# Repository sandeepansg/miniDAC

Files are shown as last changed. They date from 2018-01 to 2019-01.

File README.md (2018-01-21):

<h1 align="center"> Arduino miniDAC Module </h1> <br>

## Table of Contents
- [About](#about)
- [Social](#social)
- [License](#license)
- [Acknowledgments](#acknowledgments)

## About





**Arduino miniDAC Module** is a unipolar digital to analog converter (DAC) module built arround [LTC®2633](http://www.linear.com/product/LTC2633), which is a family of dual 12-, 10-, and 8-bit voltage-output DACs with an integrated, high accuracy, low drift reference in an 8-lead TSOT-23 package.
<br>These DACs communicate via a 2-wire I2C-compatible serial interface operating in both the standard mode (clock rate of 100kHz) and the fast mode (clock rate of 400kHz).
<br>It is compatible with both 3.3V and 5V logic levels and uses [LTC2633](https://github.com/TamojitSaha/LTC2633) library developed by [Tamojit Saha](http://tamojit.tk) and [Sandeepan Sengupta](http://sandeepan.info)
<p align="center">
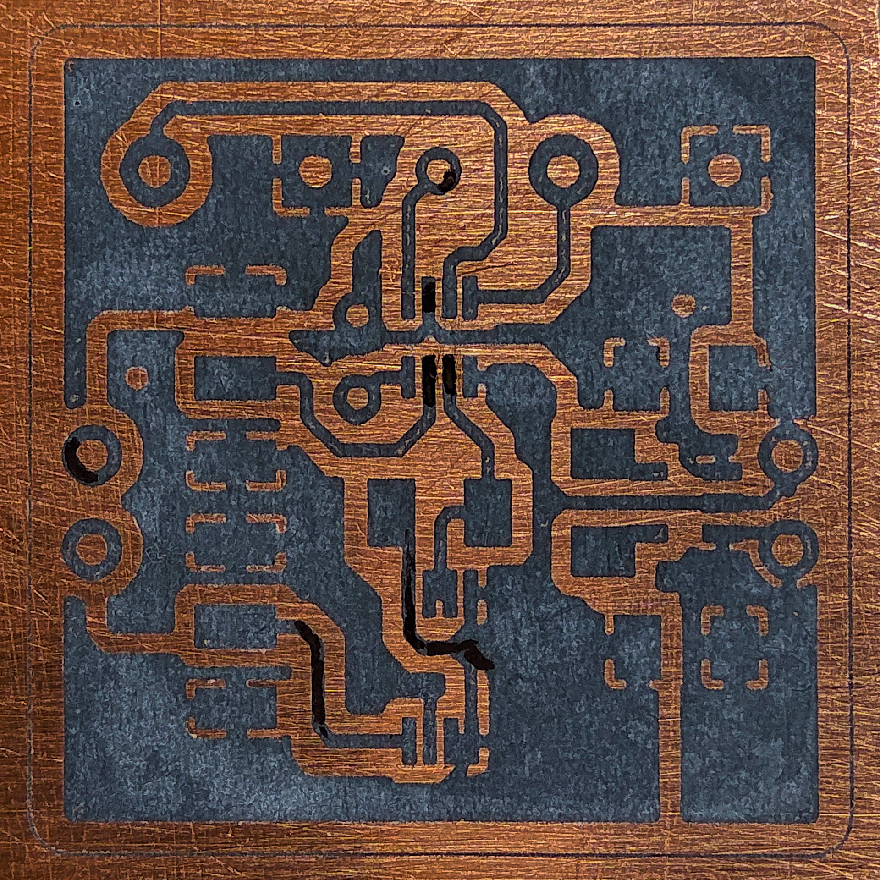
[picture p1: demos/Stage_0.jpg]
  &nbsp
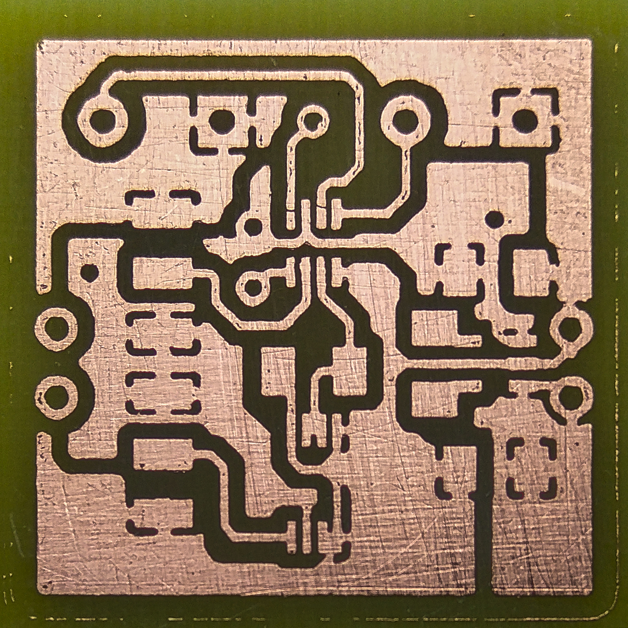
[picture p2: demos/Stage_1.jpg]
  &nbsp
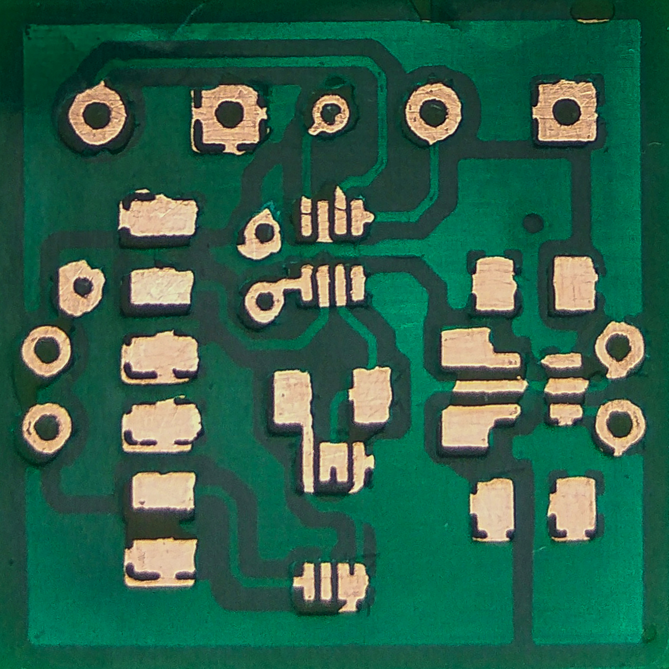
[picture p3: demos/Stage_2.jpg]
  &nbsp
</p>
<p align="center">
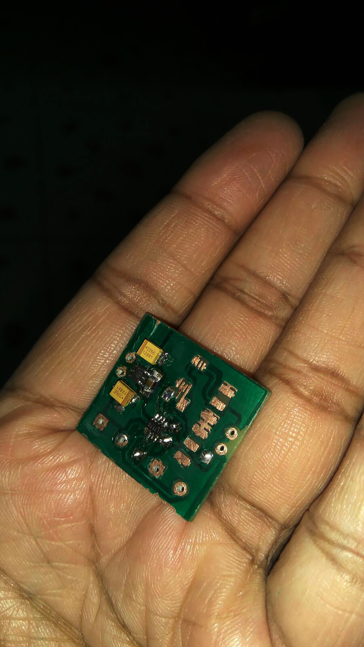
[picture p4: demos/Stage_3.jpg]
  &nbsp 
  &nbsp
</p>

## Social
Connect us here:
<br><br>
 <br>
 
<p> 
or <a href ="https://github.com/TamojitSaha/LTC2633/issues/new/">file an issue</a>. Feature requests are always welcome.</p>

## License
Contents of this repository are realeased under [CC-BY-NC-SA 4.0](./LICENSE.md) <br>


## Acknowledgments
Thanks to the contributors! :wink:

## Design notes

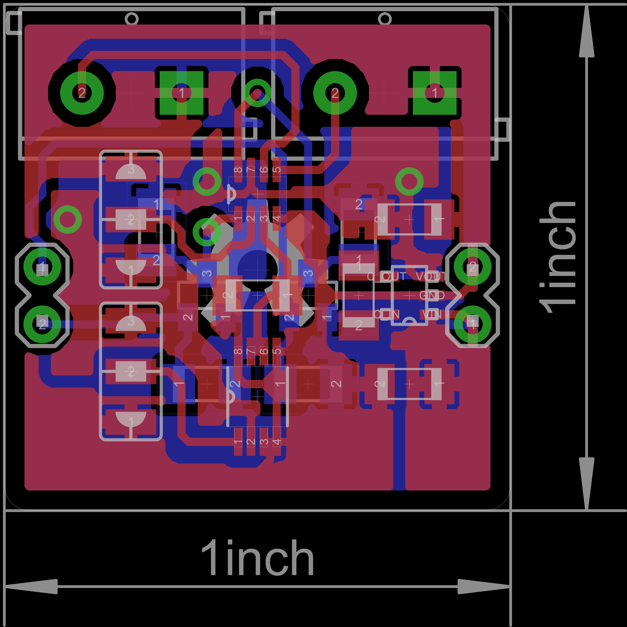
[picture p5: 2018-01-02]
demos/brd.png

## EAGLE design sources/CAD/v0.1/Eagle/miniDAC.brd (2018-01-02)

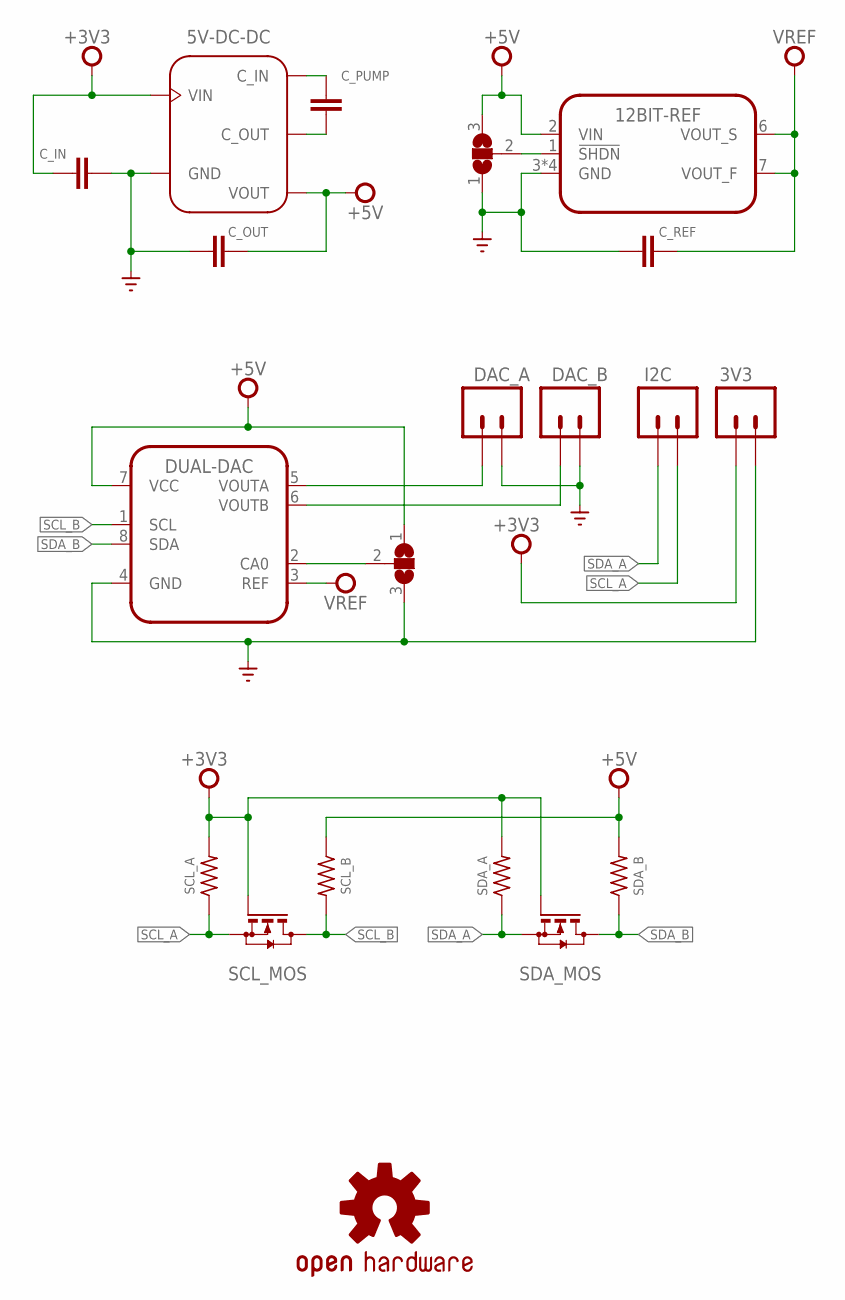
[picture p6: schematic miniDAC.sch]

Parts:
3V3: M02LOCK; 1X02_LOCK
5V-DC-DC: LTC1517CS5-5#PBF; SOT-23_S5
12BIT-REF: LTC6655CHMS8-5PBF; SOP65P490X110-8N
ADDR_SEL: SJ2WW; SJ_2W
C_IN: 3.3uF; C1206K
C_OUT: 6.8uF; C1206K
C_PUMP: 0.1uF; C1206K
C_REF: 10uF; C1206K
DAC_A: M025MM; SCREWTERMINAL-5MM-2
DAC_B: M025MM; SCREWTERMINAL-5MM-2
DUAL-DAC: LTC2633CTS8-HZ8PBF; SOT65P280X100-8N
I2C: M02LOCK; 1X02_LOCK
OSHW: OSHW-LOGOL; OSHW-LOGO-L
REF_SEL: SJ2WW; SJ_2W
SCL_A: 2.7K; M1206
SCL_B: 1.3K; M1206
SCL_MOS: BSS123; SOT23
SDA_A: 2.7K; M1206
SDA_B: 1.3K; M1206
SDA_MOS: BSS123; SOT23

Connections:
!SHDN: 12BIT-REF.1 (!SHDN), REF_SEL.2
+3V3: 3V3.1, 5V-DC-DC.VIN, C_IN.1, SCL_A.2, SCL_MOS.1 (G), SDA_A.2, SDA_MOS.1 (G)
+5V: 5V-DC-DC.VOUT, 12BIT-REF.2 (VIN), ADDR_SEL.1, C_OUT.2, DUAL-DAC.7 (VCC), REF_SEL.3, SCL_B.1, SDA_B.2
CA0: ADDR_SEL.2, DUAL-DAC.2 (CA0)
C_IN: 5V-DC-DC.C_OUT (C_IN), C_PUMP.1
C_OUT: 5V-DC-DC.C_IN (C_OUT), C_PUMP.2
DAC_A: DAC_A.2, DUAL-DAC.5 (VOUTA)
DAC_B: DAC_B.2, DUAL-DAC.6 (VOUTB)
GND: 3V3.2, 5V-DC-DC.GND, 12BIT-REF.3 (GND), 12BIT-REF.4 (GND), 12BIT-REF.5 (GND), 12BIT-REF.8 (GND), ADDR_SEL.3, C_IN.2, C_OUT.1, C_REF.2, DAC_A.1, DAC_B.1, DUAL-DAC.4 (GND), REF_SEL.1
SCL_A: I2C.2, SCL_A.1, SCL_MOS.2 (S)
SCL_B: DUAL-DAC.1 (SCL), SCL_B.2, SCL_MOS.3 (D)
SDA_A: I2C.1, SDA_A.1, SDA_MOS.2 (S)
SDA_B: DUAL-DAC.8 (SDA), SDA_B.1, SDA_MOS.3 (D)
VREF: 12BIT-REF.6 (VOUT_S), 12BIT-REF.7 (VOUT_F), C_REF.1, DUAL-DAC.3 (REF)

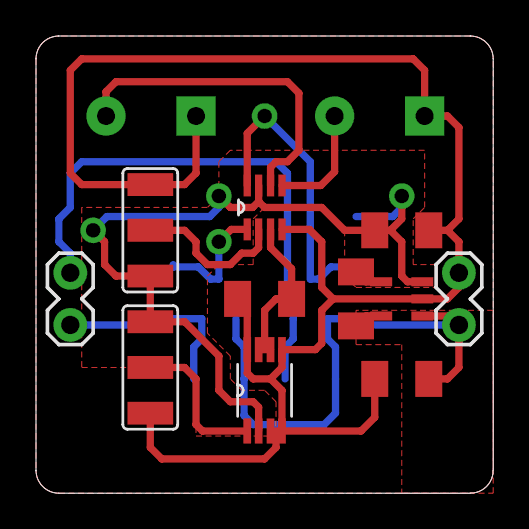
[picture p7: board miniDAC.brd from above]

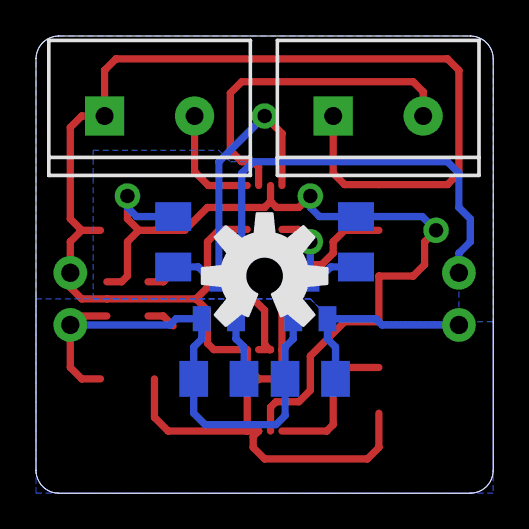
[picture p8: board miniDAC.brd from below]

Board: 2 copper layers, 25.4 x 25.4 mm, 20 parts (9 on the bottom side), 14 nets.

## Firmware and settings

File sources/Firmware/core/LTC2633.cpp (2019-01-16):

/*
    @file     LTC2633.cpp
    @author   Sandeepan Sengupta (http://sandeepan.info),
              Tamojit Saha(http://tamojitsaha.info)

    Arduino library part file for miniDAC module
    Designed for Linear Technology LTC®2633

    ************************************************
    About LTC®2633
    ************************************************
    The LTC®2633 is a family of dual 12-, 10-, and 8-bit voltage-output DACs with an integrated, high accuracy, low drift reference in an 8-lead TSOT-23 package.

    These DACs communicate via a 2-wire I2C-compatible serial interface. The LTC®2633 operates in both the standard mode (clock rate of 100kHz) and the fast mode (clock rate of 400kHz).
    *************************************************

    Version: 1.0.0
    Released under CC-BY-NC-SA 4.0 (https://creativecommons.org/licenses/by-nc-sa/4.0/legalcode)
    All text above, must be included in any redistribution
*/

#if ARDUINO >= 100
#include "Arduino.h"
#else
#include "WProgram.h"
#endif

#include <Wire.h>
#include "LTC2633.h"



LTC2633::LTC2633()
{

}

void LTC2633::configure(configuration _cfg)
{
  /*
    Takes 8bits of I2C Address (Data Type: "address")
    and
    DAC resolution in bit(s) (Data Type: "resolution")
    and
    I2C transfer rate as input(s) (Data Type: "rate")
  */
  Wire.begin();
  Wire.setClock(_cfg.Rate);
  Wire.end();
  adrs = _cfg.Address;
  rsln = _cfg.Resolution;
}

void LTC2633::setRate(rate _rte)
{
  /*
    Sets I2C transfer rate (clock frequency)
  */
  Wire.begin();
  Wire.setClock(_rte);
  Wire.end();
}

void LTC2633::setResolution(resolution _rsl)
{
  /*
    Sets DAC resolution
  */
  rsln = _rsl;
}

void LTC2633::volt(uint64_t data, DAC dac)
{
  /*
     Stores data to DAC register of LTC®2633
     Takes 64bit unsigned integer (unsigned long long int) and "DAC" (8bits of DAC register address) as input
     Manipulates the data using dataman() and uses wireman() to transmit it using I2C bus
  */
  uint8_t code = (write_update_dac << 4) | dac;
  dataman(data);
  wireman(code, byte(data_high), byte(data_low));
}

void LTC2633::load(DAC dac)
{
  /*
     Instructs LTC®2633 to transfer its input register data to DAC register address
     Takes "DAC" (8bits of DAC register address) as input
     Uses control() to transmit the instruction using I2C bus
  */
  uint8_t code = (write_input_reg << 4) | dac;
  control(code);
}

void LTC2633::store(uint64_t data, DAC dac)
{
  /*
     Stores data to input register of LTC®2633
     Takes 64bit unsigned integer (unsigned long long int) and "DAC" (8bits of DAC register address) as input
     Manipulates the data using dataman() and uses wireman() to transmit it using I2C bus
  */
  dataman(data);
  wireman(dac, data_high, data_low); /*Actually it should be -> wireman(((write_input_reg << 4) | dac), data_high, data_low)*/
}

void LTC2633::powerOff(void)
{
  /*
     Instructs LTC®2633 to power off completely
     Uses control() to transmit the instruction using I2C bus
  */
  uint8_t code = power_down_all;
  control(code);
}

void LTC2633::powerDown(DAC dac)
{
  /*
     Instructs LTC®2633 to power down its individual DAC
     Takes "DAC" (8bits of DAC register address) as input
     Uses control() to transmit the instruction using I2C bus
  */
  uint8_t code = (power_down_dac << 4) | dac;
  control(code);
}

void LTC2633::internalReference(void)
{
  /*
     When called, it instructs LTC®2633 to switch to internal reference mode and allows user to use the DAC with internal reference voltage
  */
  uint8_t code = (internal_reference << 4) | 0x0f;
  control(code);
}

void LTC2633::externalReference(void)
{
  /*
     When called, it instructs LTC®2633 to switch to external reference mode and allows user to use the DAC with external reference voltage
  */
  uint8_t code = (external_reference << 4) | 0x0f;
  control(code);
}

void LTC2633::control(uint8_t code)
{
  /*
     DECLARED IN PRIVATE : RESTRICTED ACCESS !!!
     Takes 8bits of number representing instruction (byte)
     Transfers it to LTC®2633 over I2C but using WIRE_WRITE
  */
  Wire.begin(adrs);
  WIRE_WRITE(code);
  Wire.end();
}

void LTC2633::wireman(uint8_t code, uint8_t data_high, uint8_t data_low)
{
  /*
     DECLARED IN PRIVATE : RESTRICTED ACCESS !!!
     Takes three 8bits of number representing instruction (byte), higher data bits and lower data bits
     Transfers them to LTC®2633 over I2C but using WIRE_WRITE in three packets
  */
  Wire.begin(adrs);
  WIRE_WRITE(code);
  WIRE_WRITE(data_high);
  WIRE_WRITE(data_low);
  Wire.end();
}

void LTC2633::dataman(uint64_t data)
{
  /*
     DECLARED IN PRIVATE : RESTRICTED ACCESS !!!
     Data manager and manipulator
     Takes 64bit unsigned integer (unsigned long long int)
     Constrains it in range relative to initialized resolution and segments in two 8bits of unsigned integer (declared in private)
  */
  uint16_t Data = (uint16_t)constrain(data, 0, pow(2, rsln)); /*Constraining data in range relative to resolution*/;

  Data = Data << (16 - rsln);

  data_high = Data >> 8;
  data_low  = Data & 0xff;
}

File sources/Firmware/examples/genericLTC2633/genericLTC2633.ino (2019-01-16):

/*
  @file     genericLTC2633.ino
  @author   Sandeepan Sengupta (http://sandeepan.info),
              Tamojit Saha(http://tamojitsaha.info)

  Arduino demonstration file for miniDAC module
  Designed for Linear Technology LTC®2633

  ************************************************
  About LTC®2633
  ************************************************
  The LTC®2633 is a family of dual 12-, 10-, and 8-bit voltage-output DACs with an integrated, high accuracy, low drift reference in an 8-lead TSOT-23 package.

  These DACs communicate via a 2-wire I2C-compatible serial interface. The LTC®2633 operates in both the standard mode (clock rate of 100kHz) and the fast mode (clock rate of 400kHz).
  *************************************************

  WARNING #1: Parts with the following markings MUST have Vcc in the range between 4.5V and 5.5V

  +------+---------+-----------------------------+
  | Bits | Marking |       Part Number(s)        |
  +------+---------+-----------------------------+
  |   12 | LTFTF   | LTC2633A-HI12, LTC2633-HI12 |
  |      | LTFTD   | LTC2633A-HZ12, LTC2633-HZ12 |
  +------+---------+-----------------------------+
  |   10 | LTFTM   | LTC2633-HI10                |
  |      | LTFTK   | LTC2633-HZ10                |
  +------+---------+-----------------------------+
  |    8 | LTFTS   | LTC2633-HI8                 |
  |      | LTFTR   | LTC2633-HZ8                 |
  +------+---------+-----------------------------+

  Version : 1.0.0
  Released under CC-BY-NC-SA 4.0 (https://creativecommons.org/licenses/by-nc-sa/4.0/legalcode)
  All text above, must be included in any redistribution
*/

#include <LTC2633.h>
#define __resolution 12 //demo only

LTC2633 myDAC;                  /*declare*/

/*
  NOTE #1:  Please find the custom datatype used in this library in table given below
  +-------------+--------------------------------+---------------+
  |  Data Type  |              Values            |  Description  |
  +-------------+--------------------------------+---------------+
  |             | FAST, fast,                    |    Set        |
  |  rate       | SLOW, slow,                    |  I2C Speed    |
  +-------------+--------------------------------+---------------+
  |             | VIII, viii, eight, EIGHT       |     Set       |
  |  resolution | X, x, ten, TEN                 |     DAC       |
  |             | XII, xii, twelve, TWELVE       |   Resolution  |
  +-------------+--------------------------------+---------------+
  |             | NC, nc,                        |               |
  |             | GND, gnd,                      |               |
  |  address    | VCC, vcc,                      | Select DAC    |
  |             | ALL, all,                      | address (I2C) |
  |             | GLOBAL, global                 |               |
  +-------------+--------------------------------+---------------+
  |configuration| various                        |  Structure    |
  +-------------+--------------------------------+---------------+
  
  NOTE #2:  The members(s) of the structure of "configuration" data type
  with coresponding member data type(s) described below
  
  +---------------+------------+--------------+
  |   Structure   | Member(s)  | Data Type(s) |
  +---------------+------------+--------------+
  |               | Rate       | rate         |
  | configuration | Address    | address      |
  |               | Resolution | resolution   |
  +---------------+------------+--------------+

  NOTE #3:  Please follow the keyword table given below
  +#######################################################################+
  +--------------+--------------+-----------------------------------------+
  |              |              | write_input_reg, update_dac_reg,        |
  |              | DATA, data,  | write_update_all, write_update_dac,     |
  | Extras       | VALUE, value | power_down_dac, power_down_all,         |
  |              |(free for use)| internal_reference, external_reference, |
  |              |              | no_operation                            |
  +--------------+--------------+-----------------------------------------+
*/

void setup()
{
  myDAC.configure();
  /*
    ABOUT : Confiure I2C transfer rate, DAC address and DAC resolution

    USAGE : Takes structure of data (data type: "configuration") having members:
              I2C transfer rate as input(s) (Data Type: "rate")
              and
              8bits of I2C Address (Data Type: "address")
              and
              DAC resolution in bit(s) (Data Type: "resolution")

    ACCEPTED FORMATS :
    <put name here>.configure();
    <put name here>.configure(Configuration);
      GIVEN :
      configuration Configuration = {slow};
      configuration Configuration = {.Rate = slow};
      configuration Configuration = {slow, global};
      configuration Configuration = {.Rate = slow, .Address = global};
      configuration Configuration = {slow, global, XII};
      configuration Configuration = {.Rate = slow, .Address = global, .Resolution = XII};

    EXAMPLES:
    myDAC.configure();
    //Switch 'myDAC' to default configuration:
      //Address = GLOBAL (0x73)
      //Resolution = XII (0x0C)
      //Rate = slow (0x0186A0)

    myDAC.configure({slow});
    //Switch 'myDAC' to given configuration:
      //Rate = slow (0x0186A0)

    myDAC.configure({.Address = VCC, .Resolution = XII});
    //Switch 'myDAC' to given configuration:
      //Address = VCC (0x12),
      //Resolution = XII (0x0C)

    myDAC.configure({slow, VCC, XII});
    //Switch 'myDAC' to given configuration:
      //Rate = slow (0x0186A0),
      //Address = VCC (0x12),
      //Resolution = XII (0x0C)

    configuration Configuration = {.Rate = slow, .Address = VCC, .Resolution = XII};
    myDAC.configure(Configuration);
    //Switch 'myDAC' to given configuration:
      //Rate = slow (0x0186A0),
      //Address = VCC (0x12),
      //Resolution = XII (0x0C)
  */

  myDAC.setRate();
  /*
    ABOUT : Set I2C clock frequency

    USAGE : Takes "rate" (transfer rate in Hz) as input

    ACCEPTED FORMATS :
    <put name here>.setRate();
    <put name here>.setRate(Rate);

    EXAMPLES:
    myDAC.setRate();               //Set I2C clock frequency to 100KHz (default)
    myDAC.setRate(FAST);           //Set I2C clock frequency to 400KHz
  */
  myDAC.setResolution();
  /*
    ABOUT : Defines LTC®2633 resolution

    USAGE : Takes "resolution" (resolution value in bits) as input

    ACCEPTED FORMATS :
    <put name here>.setResolution();      		//Defines resolution as 12 bits (default)
    <put name here>.setResolution(Resolution);	//Defines resolution as user specifies with proper keyword

    Note #4: Unless changed by calling function with proper resolution(Keyword) listed below, system initializes to 12 bits resolution setup.

    +--------------------------+-------------------------------+
    |         Keyword          |          Operation            |
    +--------------------------+-------------------------------+
    | viii, VIII, eight, EIGHT | Defines resolution as 8 bits  |
    | x, X, ten, TEN           | Defines resolution as 10 bits |
    | xii, XII, twelve, TWELVE | Defines resolution as 12 bits |
    +--------------------------+-------------------------------+

    WARNING #2: Even when using these function, make sure it matches to the particular LTC®2633 variant to avoid unexpected behavior.

    Please verify markings on IC with the following table:

    +------+------------------------------------------+
    | Bits |                 Marking(s)               |
    +------+------------------------------------------+
    |   12 | LTFTC, LTFTB, LTFSZ, LTFTV, LTFTF, LTFTD |
    |   10 | LTFTJ, LTFTH, LTFTG, LTFTW, LTFTM, LTFTK |
    |    8 | LTFTQ, LTFTP, LTFSZ, LTFTN, LTFTS, LTFTR |
    +------+------------------------------------------+

    EXAMPLES:
    myDAC.setResolution();      //Defines resolution as 12 bits
    myDAC.setResolution(X);		//Defines resolution as 10 bits
  */

  myDAC.externalReference();
  /*
    ABOUT : Instructs LTC®2633 to switch to external reference mode and allows user to use the DAC with external reference voltage

    USAGE : It's a void type function can be used just by calling it

    ACCEPTED FORMAT:
    <put name here>.externalReference();

    EXAMPLE:
    myDAC.externalReference()   //For 'myDAC'
  */

  /*
    Note #5:  The following parts have POWER-ON REFERANCE MODE set to external reference.

    WARNING #3: Either use external voltage reference IC or remember switching to internal reference mode while using these parts.

    +------+------------------------------+---------+
    | Bits |        Part Number(s)        | Marking |
    +------+------------------------------+---------+
    |   12 | LTC2633A-LX12, LTC2633A-LX12 | LTFTB   |
    |   10 | LTC2633-LX10                 | LTFTH   |
    |    8 | LTC2633-LX8                  | LTFTP   |
    +------+------------------------------+---------+
  */

  myDAC.internalReference();
  /*
    ABOUT : Instructs LTC®2633 to switch to internal reference mode and allows user to use the DAC with internal reference voltage

    USAGE : It's a void type function can be used just by calling it

    ACCEPTED FORMAT:
    <put name here>.internalReference();

    EXAMPLE:
    myDAC.internalReference();  //For 'myDAC'
  */
}

void loop()
{
  uint64_t value = random(0, pow(2, __resolution)); /*generate a random number in range (for testing purposes only)*/

  myDAC.store(value);
  /*
    ABOUT : Stores value to input register of LTC®2633

    USAGE : Takes 64bit unsigned integer (unsigned long long int)
            and
            "DAC" (8bits of DAC register address) as input(s)

    ACCEPTED FORMATS:
    <put name here>.store(VALUE);
    <put name here>.store(VALUE, DAC);

    EXAMPLES:
    myDAC.store(value);         //Given, 'value' is supplied, switch 'myDAC' to default configuration: DAC = BOTH
    myDAC.store(value, DAC0);   //For 'myDAC', 'value' must be supplied
  */

  myDAC.load(BOTH);
  /*
    ABOUT : Instructs LTC®2633 to transfer its input register data to respective DAC register

    USAGE : Takes "DAC" (8bits of DAC register address) as input as input

    Note #6 : Recommended to use after 'value' is '<put name here>.store()' -ed earlier

    ACCEPTED FORMATS:
    <put name here>.load();
    <put name here>.load(dac);

    EXAMPLES:
    myDAC.load();               //Switch 'myDAC' to default configuration: dac = BOTH
    myDAC.load(DAC0);
  */

  myDAC.volt(value, both);
  /*
    ABOUT : Stores 'value' to DAC register of LTC®2633

    USAGE : Takes 64bit unsigned DATA (unsigned long long int)
            and
            "DAC" (8bits of DAC register address) as input(s)

    ACCEPTED FORMATS:
    <put name here>.volt(VALUE);
    <put name here>.volt(value, dac);

    EXAMPLES:
    myDAC.volt(VALUE);          //Given, 'value' is supplied, switch 'myDAC' to default configuration: dac = BOTH
    myDAC.volt(value, DAC0);    //For 'myDAC', 'value' must be supplied
  */

  myDAC.powerDown();
  /*
    ABOUT : Instructs LTC®2633 to power down its individual DACs

    USAGE : Takes "DAC" (8bits of DAC register address) as input as input

    ACCEPTED FORMATS:
    <put name here>.powerDown();
    <put name here>.powerDown(dac);

    EXAMPLES:
    myDAC.powerDown();          //Switch 'myDAC' to default configuration: dac = BOTH
    myDAC.powerDown(DAC0);      //For 'myDAC'
  */

  myDAC.powerOff();
  /*
    ABOUT : Instructs LTC®2633 to power off completely

    USAGE : It's a void type function can be used just by calling it

    ACCEPTED FORMAT:
    <put name here>.powerDown();

    EXAMPLE:
    myDAC.powerOff();           //For 'myDAC'
  */
}

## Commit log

2018-01-02 Bulk Upload
    Uploaded everything
    [miniDAC.brd, miniDAC.sch]
2018-01-02 Added ZIP library
    Arduino library manager compatible zip file added

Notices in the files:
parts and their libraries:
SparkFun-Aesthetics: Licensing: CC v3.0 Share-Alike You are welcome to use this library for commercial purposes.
